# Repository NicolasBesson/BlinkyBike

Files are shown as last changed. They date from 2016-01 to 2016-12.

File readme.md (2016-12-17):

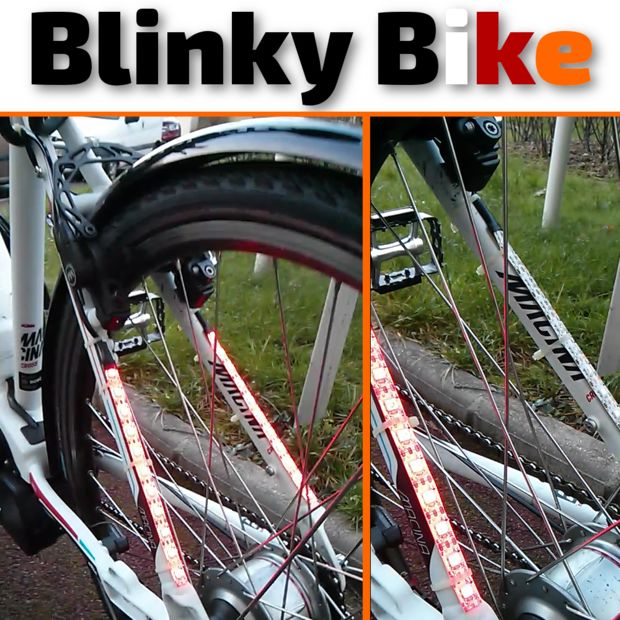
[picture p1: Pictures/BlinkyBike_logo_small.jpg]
BlinkyBike Logo Blinky Bike Logo


When ridding for your commute or for pleasure, being visible on the road is always a nightmare, as either your bike light system in daylight is not visible, or because drivers never know when you turn in night conditions.

The Blinky Bike project is the ultimate solution to add light system to any Bike, (and electric Bike) using a 5V power bank or the onboard bike Battery. It relies on NeoPixel LEDs (WS2812) flexible stripes, for the Front and Rear. The system based on an Atmel ATtiny 85 micro-controller, and allows different light modes that can be selected using two water proof switches (One for the Left hand and one for the Right hand).

## Project Award
Instructables Logo 

The Blinky Bike project has been awarded of the **First Prize** in June 2016 for the Instructables' Bike contest 2016.
You can check out the Instructables article [here](http://www.instructables.com/id/Blinky-Bike-a-Light-System-for-Bikes/).

## Device Usage
The device Left and Right buttons are the only interface with the system allowing to :

* Turn ON and OFF the light system
* Turn Left and Right indicator
* Extend the Left and Right indicator blink duration

Switches operations are :

| Left Button | Right Button | Action |
|:---:|:---:|:---:|
| Release | Release | Nothing |
| Short | Release | Turn Left or extend turn light indicator  |
| Release | Short | Turn Right or extend turn light indicator |
| Long | Long | Turn Light ON or OFF |

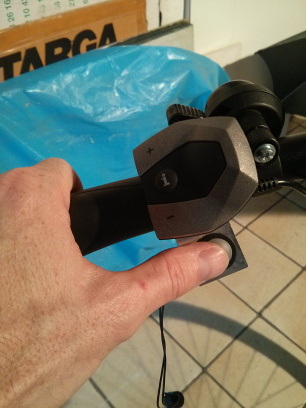
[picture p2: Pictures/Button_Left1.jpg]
BlinkyBike Left Button Left Button
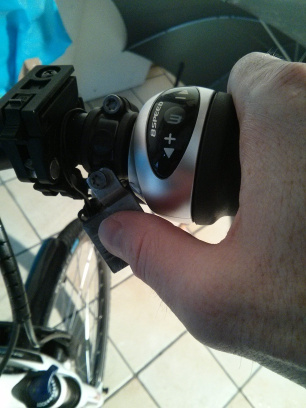
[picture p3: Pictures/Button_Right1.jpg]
BlinkyBike Right Button Right Button
 

## LEDs stripes
The system is based on a Front LED flexible stripe and two Rear LED Flexible Stripe, one for the Left and one for the Right indicator.
The Front and Rear LEDs stripes are composed of a total of 30 LEDs, 8 for the Front and 11 for each Rear stripes.

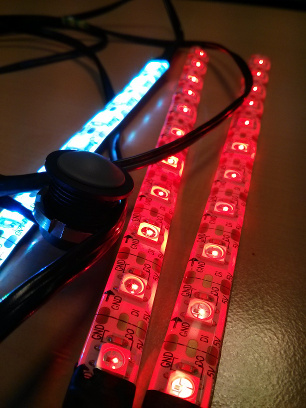
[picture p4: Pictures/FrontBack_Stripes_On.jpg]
BlinkyBike Schematic Front and Rear Stripes


## Power consideration
The system is designed to be power friendly with the e-Bike battery, as the battery might not be able to provide the full power required to have all the LEDs turned on at the same time. As the NeoPixel RGB LEDs (WS2812) consumes 20 mA per color channel, with a total of 60 mA (3 channels * 20 mA) when the LED is turned full bright White color (Red = 255, Green = 255, Blue = 255). The challenge is to not consume over than 500 mA (power limit supplied by the Battery on my e-Bike). For this, I have applied a secure level set to 450 mA as maximum. Leading then to a limit of 7 LEDs at Full White Bright active at a time.
Having only 7 LEDs is really limitating for a bike light system, the solution is then to multiplex the LEDs and ensure that only those 7 LEDs are on at time, while all the others are off. If the multiplexing switch is performed fast enough, it should be possible to make it not visible for a Human eye.
This upper limit is valid when the color of all the LEDs is set to White color with 100% intensity. With traditional road light of cars, for exemple, with a White color for the head light and Red color for the rear lights, then this limits of 7 LEDs is broken, as White is Red, Grenn and Blue channels set to maximum, and Red color means only a Red channel set to maximum, reduce the total power consumption of the Red LED to 20 mA.
Therefore, the ATtiny firmware is taking care of the current limitation by switching on and off the LEDs, remaining only 9 LEDs on at a time, giving a maximum power consumption for the LEDs of XXX mA.

This can be adjusted by editing the [Stripes.h](/BlinkyBike/BlinkyBike/Stripes.h) file :
```c
// Number of LED
#define LED_STRIPE_FRONT_ON   3
#define LED_STRIPE_REAR_ON    6
```

## Light animation
When riding a bike a night, and having fix light color is not the optimal solution to be visible by drivers. Therefore having some flashing, blinking mode for the lights gives more visibility and make your bike more attractive. When light is On, the Front stripe displays a fast blinking animation at a frequency of about 10 Hz.
When turning left or right, the visual animation is orange and blinky.
So having a flexible software architecture is a must have. With AnimationStep and Animation it is fairly simple to describe an animation. 

The types are described as following :
```c
struct AnimationStepFront
{
	unsigned long StepDuration;	// Step Duration in ms
	PixelColor Pixels;		// Step Pixels color
};

struct AnimationFront
{
	AnimationStepFront *animationStep;	// Front Step
	AnimationFront *nextAnimation;		// Next Front animation
};
```

And an animation is described as following :
```c
AnimationStepFront stepWhiteFront = { 150, COLOR_PIXEL(WHITE) };
AnimationStepFront stepBlackFront = { 50, COLOR_PIXEL(BLACK) };

/* Animations for Front */
AnimationFront animationFrontOff = { &stepBlackFront, &animationFrontOff };
AnimationFront animationFrontOn = { &stepWhiteFront, &animationFrontOn };

```

# Building the Hardware
The hardware is minimalistic as the Neopixel and ATTiny are embedding all the discrete components that you normally use to drive RGB LED.

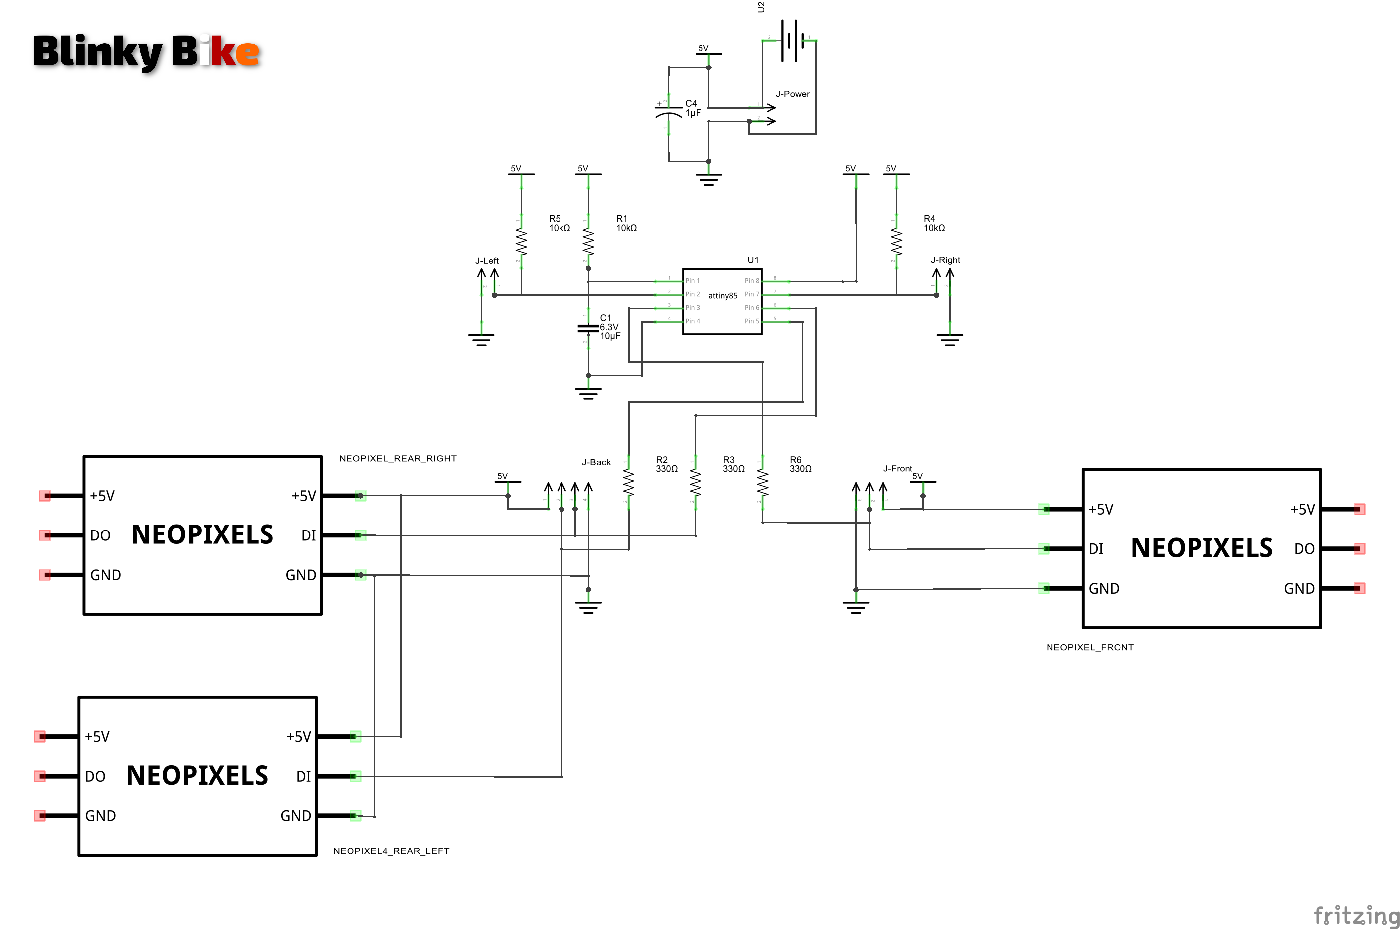
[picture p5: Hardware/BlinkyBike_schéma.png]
BlinkyBike Schematic Schematic


The Blinky Bike system is built using the following hardware :

* ATtiny85
* NeoPixel Stripes
 * 1x 8 LEDs
 * 2x 11 LEDs
* 3x 380 Ohms resistor
* 1x 10 kOhms resistor
* 1x 1000 µF capacitor
* 2x water proof switches

You won't find any PCB layout, as I'm using through hole prototyping board, developed with Fritzing software.

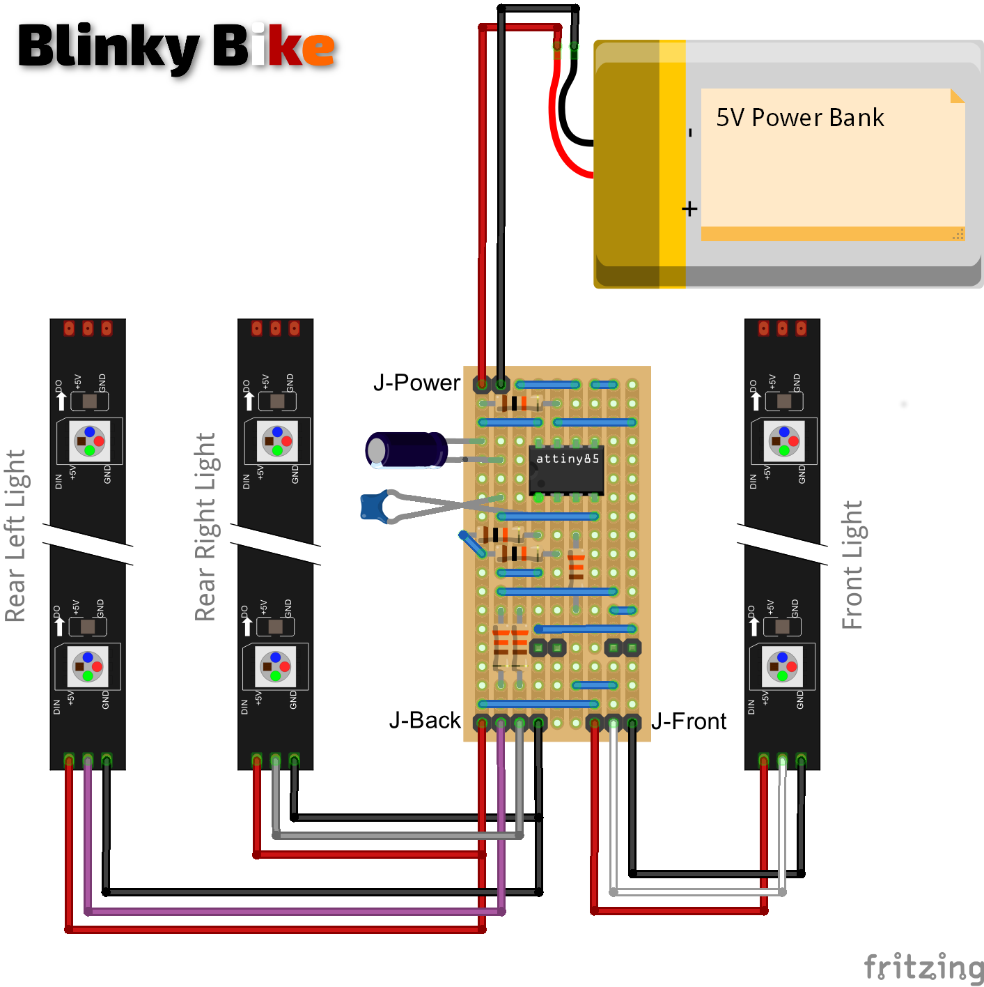
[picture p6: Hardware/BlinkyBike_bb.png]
Prototyping board


# Building the Software
The ATtiny 85 is a really cool Micro Controller that have 8 KB of Flash and 512 B of RAM to run any kind of C or C++ software. This gives some space to run a simple software and for this reason some optimization are required.

The project has been developed in C++ (C++11) in order to reuse and give more flexibility in case of development of new features. It is required to use the VisualMicro extension for Visual Studio 2013 in order to build the project.

AdaFruit is providing a library to drive the Neopixel devices, that you can directly integrate in your Arduino IDE. But this code has been designed to support various modes in order to address major use cases. The source code repository is containing an optimized version that works only with the Neopixels that I have selected and might not work if you choose a different one.

The Neopixel device requires specific timings that can't be reach when using the ATtiny 85 in 4 MHz (its default configuration) and therefore requires to use the 8 Mhz mode. So it is mandatory to burn the correct fuses in the ATtiny before deploying the firmware. This can be done from the Arduino IDE by selecting the ATtiny 85 target and selecting the clock frequency to 8 MHz (internal).

## Tools
Before starting some tools are required :

* [Arduino IDE](https://www.arduino.cc/en/Main/Software)
* Visual Studio 2015 Community Edition (and other flavors)
* [VisualMicro](http://www.visualmicro.com/) a Visual Studio plugin for Arduino development
* USBTinyISP programer

Install Visual Studio 2015, and make sure to select the support for C++ (Visual C++) during installation.

Install the Arduino IDE application, and launch the application. You first need to add the support of the ATtiny familly as by default only Arduino based platforms are supported. From the File menu, select the Preferences submenu, and then find the “Additional Boards Manager URLs” field near the bottom of the dialog. Add the following url : https://raw.githubusercontent.com/damellis/attiny/ide-1.6.x-boards-manager/package_damellis_attiny_index.json
You can then validate and close the preferences dialog box. Then from the Tools menu you have to :

* Select the Board entry and choose **Board Manager** to add ATtiny board support.
* Select **ATtiny** as Board
* Select **ATtiny85** as Processor
* Select **16MHz (Internal)** as Clock or **8MHz (Internal)** as Clock
* Select **USBtinyISP** as Programmer

Close the **Arduino IDE** application and install the Visual Micro plugin for Visual Studio.
Launch **Visual Studio** and open the BlinkyBike.sln from the project folders.
On first usage of Visual Micro, you have to configure the various parameters of the plugin.

* Select the version of the IDE you select
* Enter the path to the tool installation folder

Then validate the configuration window and access the Visual Studio IDE. From vMicro menu :

* Select **ATtiny w/ ATtiny85** as Board
* Select **Internal 16MHz** or **Internal 8MHz** as Option2 (based on the Fuse configuration applied under Arduino IDE
* Select **USBtinyISP** as Programmer

The development environment is now ready for building and flashing.

## Compilation
The source code compiles in Visual Studio 2015 using the VisualMicro plugin and Arduino IDE (cf Tools chapter for installation details).
To compile the project you have to :

* Open the BlinkyBike\BlinkyBike.sln solution file
* From Visual Studio, select **Build** menu and choose **Configuration Manager** entry
* From the Configuration Manager window, select **Release** in the **Active solution confgiuration** drop box
* Click on the Close button to close the Configuration Manager window
* From **Build** menu select **Build Solution** entry
* Wait few seconds (usualy less than 30 seconds)
* Ensure that the last output from the Output window is : *Program size: 5,476 bytes (used 67% of a 8,192 byte maximum) (17.83 secs)* (values may vary)

Then you are ready to program your ATtiny 85.

## Programming
The ATtiny 85 micro controller can be programmed using the USBTinyISP programmer. The programmer is visible through a serial com port. You need to identify the associate port index (using Windows Device Manager) in order configure the Visual Micro plugin. 

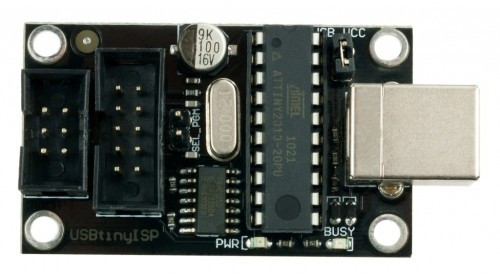
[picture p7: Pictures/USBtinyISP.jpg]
USB Tiny ISP


You need to wire the programmer as following:

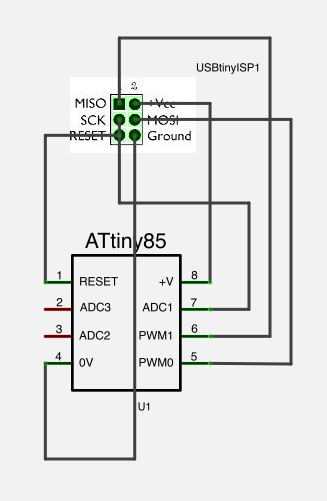
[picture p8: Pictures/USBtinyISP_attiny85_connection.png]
USB Tiny ISP with ATtiny85


# Assembling
## Left and Right Button
The Left and Right waterproof buttons are the interface for the BlinkyBike Light System management, as described earlier. It is suggested to mount them close to the Grip and Shifter to avoid ridding distractions. So for this reason, I mount them next to the shifter screw, using a stainless and steal pad as illustrated on the first fourth pictures.

BlinkyBike Left Button Left Button BlinkyBike Right Button Right Button
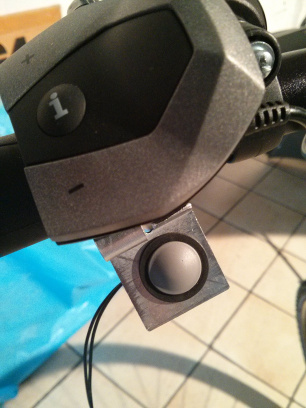
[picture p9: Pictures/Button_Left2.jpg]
BlinkyBike Left Button Left Button
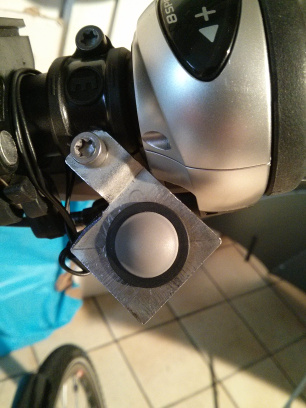
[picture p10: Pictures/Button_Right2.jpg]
BlinkyBike Right Button Right Button
 

## Front and Rear LED Stripes
To ensure a good visibility of the light, I would suggest you to stick the stripes on the Frame of the bike. For the Rear, you can use the rear frame parts that are holding the rear wheel, there is usually 15 to centimeters free, between the brake and the wheel bolt. For the Front, the head tube is the ideal spot, but you have to ensure that no brake cable is hiding even partially the LED stripe.

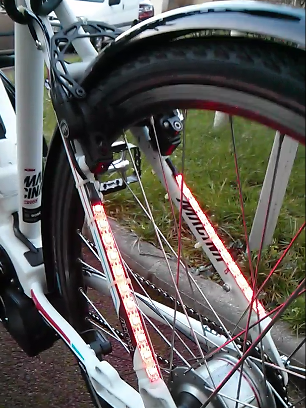
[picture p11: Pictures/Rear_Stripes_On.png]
Rear Full On
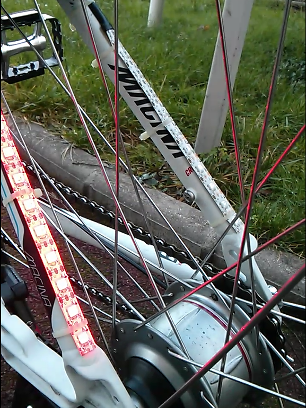
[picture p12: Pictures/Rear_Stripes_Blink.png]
Rear Blink
 

## System Casing
The PCB is small enough to fit in an aspirin tube, that have hermetic cap. Only four holes are required to get the buttons, LED stripes and power cords to get in. To maintain the packaging hermetic, then you can use hot glue inside the cap.
Once done, and enclosed correctly the tube is small enough to get fixed under the handlebar using plastic ties.

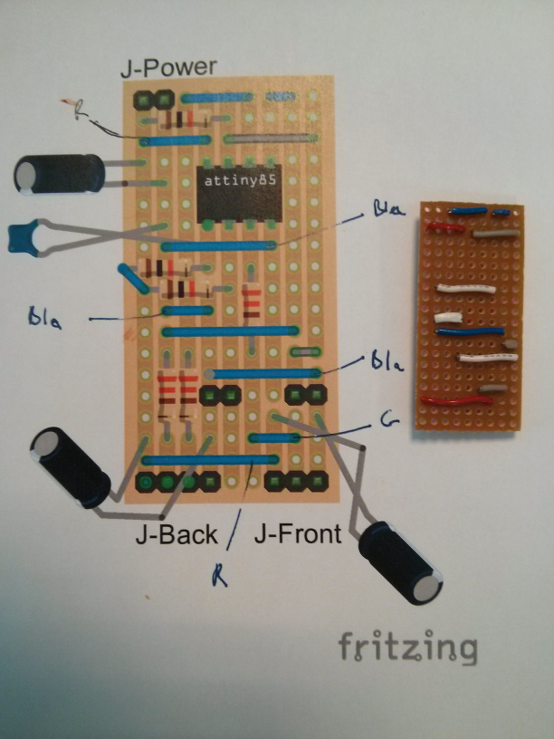
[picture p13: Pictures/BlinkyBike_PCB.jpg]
BlinkyBike PCB PCB

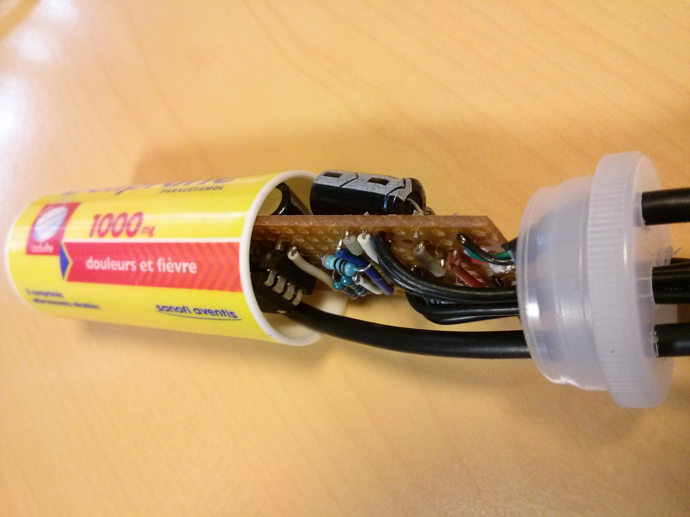
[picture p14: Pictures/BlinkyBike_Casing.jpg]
BlinkyBike Casing Casing


## Battery holder
The device is 5 Volts powered, so a USB Power Bank of 10000 mAh is a perfect solution for 3 weeks of daily commute. You can find small battery devices at your favorite store.

## Full System
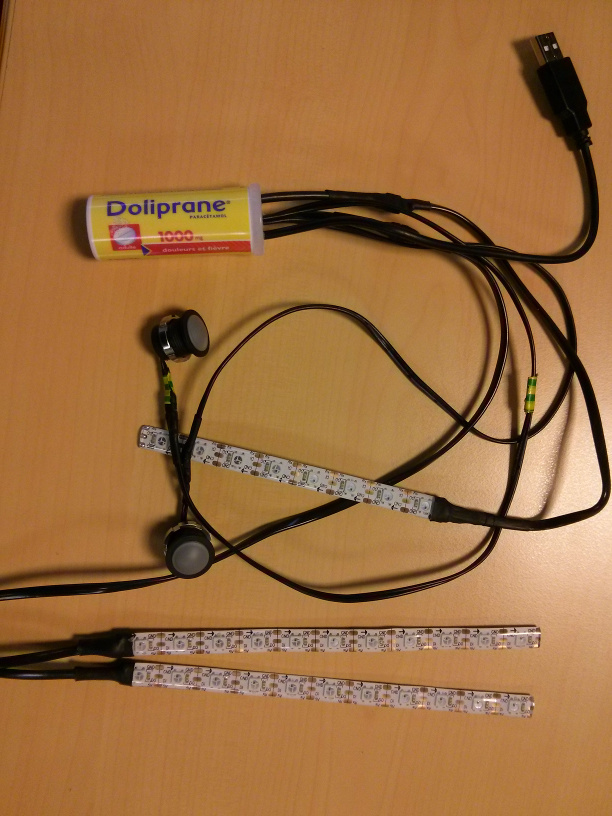
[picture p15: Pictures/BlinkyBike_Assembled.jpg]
BlinkyBike Assembled Assembled


# Revision History
## V1.3 - 2016-12-31
* Increment the number of LEDs set on at the same time
* Increasing support for CPU frequency of 8Mhz and 16 Mhz (fuse and compilation options)
* Reduced the visual flickering for the rear Light Stripes

## V1.2 - 2016-12-12
* Adding timer animation extension while pressing on left button when left animation played (same for right)
* Fix issue for Turn Left and Right light stays black after quick transitionning from Left to Right when in Light On 

## V1.1 - 2016-08-20
* Fix Left and Right flipping issue

## V1.0 - 2016-01-21
* First working prototype for the Hackster.io [article](https://www.hackster.io/nicolasbesson/blinkybike-a-flexible-light-system-for-bike-f733f0) and Instructables [article](http://www.instructables.com/id/Blinky-Bike-a-Light-System-for-Bikes/)

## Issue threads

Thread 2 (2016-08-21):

Missing pictures in documentation

NicolasBesson, 2016-08-21:
In readme.MD file there are two missing pictures in chapter https://github.com/NicolasBesson/BlinkyBike/blob/master/readme.md#front-and-rear-led-stripes

NicolasBesson, 2016-09-09:
Fixed

Closed 2016-09-09.

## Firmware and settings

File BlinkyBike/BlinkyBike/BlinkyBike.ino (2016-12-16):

/////////////////////////////////   License  //////////////////////////////////
///////////////////////////////////////////////////////////////////////////////
// Copyright 2015 - 2017 Nicolas BESSON - BeeAtHome
//
// Licensed under the Apache License, Version 2.0 (the "License");
// you may not use this file except in compliance with the License.
// You may obtain a copy of the License at
//
//     http://www.apache.org/licenses/LICENSE-2.0
//
// Unless required by applicable law or agreed to in writing, software
// distributed under the License is distributed on an "AS IS" BASIS,
// WITHOUT WARRANTIES OR CONDITIONS OF ANY KIND, either express or implied.
// See the License for the specific language governing permissions and
// limitations under the License.
//
///////////////////////////////////////////////////////////////////////////////

/******************************************************************************
 *              ____  _ _       _            ____  _ _        
 *             |  _ \| (_)     | |          |  _ \(_) |
 *             | |_) | |_ _ __ | | ___   _  | |_) |_| | _____
 *             |  _ <| | | '_ \| |/ / | | | |  _ <| | |/ / _ \
 *             | |_) | | | | | |   <| |_| | | |_) | |   <  __/
 *             |____/|_|_|_| |_|_|\_\\__, | |____/|_|_|\_\___|
 *                                    __/ |  Version 1.2      
 *                                   |___/                    
 *
 *****************************************************************************/

#if defined(ARDUINO) && ARDUINO >= 100
	#include "arduino.h"
#else
	#include "WProgram.h"
#endif

#include "Adafruit_NeoPixel.h"
#include "Timer.h"
#include "Button.h"
#include "Stripes.h"
#include "SceneManager.h"

// LED Stripes configuration
// See Stripes.h

// Buttons configuration
#define BUTTON_LEFT_PIN					3
#define BUTTON_RIGHT_PIN				2

#define BUTTON_DEBOUNCE_TIMEOUT			10
#define BUTTON_STATE_TIMEOUT			200
#define BUTTON_HOLD_TIMEOUT				(1 * 1000)

// Scenes timer index
#define SCENE_TIMER_FRONT			0
#define SCENE_TIMER_REAR_LEFT		1
#define SCENE_TIMER_REAR_RIGHT		2


// LED Stripes
Adafruit_NeoPixel frontLight		= Adafruit_NeoPixel(LED_STRIPE_FRONT_NUMLED,		LED_STRIPE_FRONT_PIN,		NEO_GRB + NEO_KHZ800);
Adafruit_NeoPixel rearLeftLight		= Adafruit_NeoPixel(LED_STRIPE_REARLEFT_NUMLED,		LED_STRIPE_REARLEFT_PIN,	NEO_GRB + NEO_KHZ800);
Adafruit_NeoPixel rearRightLight	= Adafruit_NeoPixel(LED_STRIPE_REARRIGHT_NUMLED,	LED_STRIPE_REARRIGHT_PIN,	NEO_GRB + NEO_KHZ800);

// Buttons
Button leftButton = Button(BUTTON_LEFT_PIN, BUTTON_DEBOUNCE_TIMEOUT, BUTTON_HOLD_TIMEOUT, BUTTON_STATE_TIMEOUT, BUTTON_PULLUP);
Button rightButton = Button(BUTTON_RIGHT_PIN, BUTTON_DEBOUNCE_TIMEOUT, BUTTON_HOLD_TIMEOUT, BUTTON_STATE_TIMEOUT, BUTTON_PULLUP);

// Timers
Timer appTimer = Timer();

// CPU Frequency checking
// The system requires that CPU frequency must be greater or equal to 8Mhz (suggested
// to 16Mhz) in order to handle correctly the WS2812 RGB Leds and avoid visual 
// flickering due to LED multiplexing to reduce the overal power consumption
#if (F_CPU < 8000000UL)
	#error CPU Frequency should be equal or greater than 8Mhz
#elif (F_CPU < 16000000UL)
	#warning CPU Frequency could be increased to 16Mhz for better visual rendering
#endif

/// <summary>
/// Front Timer callback function
/// </summary>
void loadSceneFront_callback()
{
	SceneManager.nextSceneStepFront();
}

/// <summary>
/// Rear Left Timer callback function
/// </summary>
void loadSceneRearLeft_callback()
{
	SceneManager.nextSceneStepRearLeft();
}

/// <summary>
/// Rear Right Timer callback function
/// </summary>
void loadSceneRearRight_callback()
{
	SceneManager.nextSceneStepRearRight();
}

// the setup function runs once when you press reset or power the board
void setup() {
	// Initialize the LED Stripes	
	frontLight.begin();
	rearLeftLight.begin();
	rearRightLight.begin();

	// Initialize the timer
	appTimer.configureTimer(SCENE_TIMER_FRONT, 2 * 1000, loadSceneFront_callback);
	appTimer.configureTimer(SCENE_TIMER_REAR_LEFT, 2 * 1000, loadSceneRearLeft_callback);
	appTimer.configureTimer(SCENE_TIMER_REAR_RIGHT, 2 * 1000, loadSceneRearRight_callback);

	// Clear the LED Stripes
	frontLight.show();
	rearLeftLight.show();
	rearRightLight.show();

	// Initialize the SceneManager
	SceneManager.begin();
}

// the loop function runs over and over again until power down or reset
void loop() {
	// Update the button state
	ButtonState leftButtonState = leftButton.getButtonState();
	ButtonState rightButtonState = rightButton.getButtonState();

	// Update the scene based on button state
	SceneManager.updateScene(leftButtonState, rightButtonState);

	// Reset short press state
	leftButton.clearButtonState();
	rightButton.clearButtonState();

	// Handle scene updates
	// Updates occurs on Timer elapsed and call to updateScene
	// Front
	if (SceneManager.isSceneUpdatedFront() == true)
	{
		// update the timer for current step duration
		appTimer.updateTimer(SCENE_TIMER_FRONT, SceneManager.getSceneStepDurationFront());
	}

	// Rear Left
	if (SceneManager.isSceneUpdatedRearLeft() == true)
	{
		// update the timer for current step duration
		appTimer.updateTimer(SCENE_TIMER_REAR_LEFT, SceneManager.getSceneStepDurationRearLeft());
	}

	// Rear Right
	if (SceneManager.isSceneUpdatedRearRight() == true)
	{
		// update the timer for current step duration
		appTimer.updateTimer(SCENE_TIMER_REAR_RIGHT, SceneManager.getSceneStepDurationRearRight());
	}

	// Update the LED Stripes
	SceneManager.updateStripes(&frontLight, &rearLeftLight, &rearRightLight);
	
	// Display the LED Stripes
	frontLight.show();
	rearLeftLight.show();
	rearRightLight.show();

	// Update timer info
	appTimer.run();
}

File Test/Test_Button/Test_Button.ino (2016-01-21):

#if defined(ARDUINO) && ARDUINO >= 100
#include "arduino.h"
#else
#include "WProgram.h"
#endif

#include <Adafruit_NeoPixel.h>
#include "Button.h"

#define NUM_LEDS	60
#define DATA_PIN	4

#define BTN_LEFT_PIN			3
#define BTN_LEFT_DEBOUNCE		10
#define BTN_LEFT_HOLD_TIMEOUT	(2*1000)
#define BTN_LEFT_STATE_TIMEOUT	(2*1000)

#define BTN_RIGHT_PIN			2
#define BTN_RIGHT_DEBOUNCE		10
#define BTN_RIGHT_HOLD_TIMEOUT	(2*1000)
#define BTN_RIGHT_STATE_TIMEOUT	(2*1000)


// Start Strip
Adafruit_NeoPixel strip = Adafruit_NeoPixel(NUM_LEDS, DATA_PIN, NEO_GRB + NEO_KHZ800);
Button buttonLeft = Button(BTN_LEFT_PIN, BTN_LEFT_DEBOUNCE, BTN_LEFT_HOLD_TIMEOUT, BTN_LEFT_STATE_TIMEOUT, BUTTON_PULLUP);
Button buttonRight = Button(BTN_RIGHT_PIN, BTN_RIGHT_DEBOUNCE, BTN_RIGHT_HOLD_TIMEOUT, BTN_RIGHT_STATE_TIMEOUT, BUTTON_PULLUP);

void setup()
{

	strip.begin();
	strip.show(); // Initialize all pixels to 'off'
	//button.setHoldThreshold(2 * 1000);
	delay(2 * 1000);
}


void loop()
{
	switch (buttonLeft.getButtonState())
	{
	case SHORT_PRESSURE:
		strip.setPixelColor(0, 255, 0, 0);
		if (strip.getPixelColor(3) == strip.Color(255, 255, 255))
		{
			strip.setPixelColor(3, 0, 0, 0);
		}
		else
		{
			strip.setPixelColor(3, 255, 255, 255);
		}
		buttonLeft.clearButtonState();
		break;
	case LONG_PRESSURE:
		strip.setPixelColor(0, 0, 255, 0);
		break;
	case RELEASED:
		strip.setPixelColor(0, 0, 0, 255);
		break;
	}

	switch (buttonRight.getButtonState())
	{
	case SHORT_PRESSURE:
		strip.setPixelColor(1, 255, 0, 0);
		break;
	case LONG_PRESSURE:
		strip.setPixelColor(1, 0, 255, 0);
		break;
	case RELEASED:
		strip.setPixelColor(1, 0, 0, 255);
		break;
	}



	strip.show();

}

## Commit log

2016-04-27 Adjusting Schematic to make it more user friendly
    [BlinkyBike.fzz]
2016-05-26 Update project assembling instructions
2016-06-10 Adding Left and Right short pressure button handling when already displaying a Left and Right animation
2016-06-29 Button modification for compiler warning removal
2016-08-21 Adding timer animation extension while pressing on left button when left animation played (same for right)
2016-08-25 Fixing compilation warning in SceneManager
    [SceneManager.h]
2016-08-25 Removing MainApp class to reduce memory footprint
2016-09-27 SceneManagerClass init function renamed to begin. Fix SceneManager.begin() not called at firmware initialization
    [BlinkyBike.ino, SceneManager.h]
2016-12-02 Adding CPU Frequency error and warning messages
    CPU Frequency checking at build
    [BlinkyBike.ino]
2016-12-02 Increase number of LED for Rear Stripes
    Reduce visual flickering by increasing the number of LED set ON for the Rear Stripes
2016-12-11 Fixing algo forcing system to start and stay in undefined state for the SceneManager internal state machine.
    [SceneManager.h]
2016-12-13 Feature Development for UI and User Experience Improvment
    * Basic execution improvement and project settings
    * Fixing compilation warning in SceneManager
    * Removing MainApp class to reduce memory footprint
    * PNG files renaming for in readme.md name match
    * Blinking duration extension capabilities
    Fixing ATtiny naming and addition of details on the blink duration extension.
    * SceneManagerClass init function renamed to begin.
    Fix SceneManager.begin() not called at firmware initialization
    * SceneManagerClass init function renamed to begin.
    Fix SceneManager.begin() not called at firmware initialization
    Forcing Light to Off at initialization
    * Fixing algo forcing system t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
    [BlinkyBike.ino, SceneManager.h]
